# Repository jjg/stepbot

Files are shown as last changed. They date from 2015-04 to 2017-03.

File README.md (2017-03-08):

#Stepbot
A simple, printable, "turtle-style" robot platform designed to be inexpensive and easy to make.

This project is a work-in-progress, all designs, circuits, software and parts are far from release-ready.

## Materials

 * 3D printed parts
 * 2 28BYJ-48 stepper motors & controller boards (I got 5 off ebay for about $10)
 * 2 tyres (those "awareness" wristbands are probably the easiest thing to find)
 * Raspberry Pi 2 (or higher)
 * Raspberry Pi Camera Module (optional)
 * Rechargable USB battery (like the ones you use to charge a phone)

## Installation 

On top of base Rasbpian install:

    sudo apt-get install -y python python-pip python-dev

    sudo pip install rpi.gpio

Use `git` to pull down this repository or, perhaps better pull the repository down on another computer and copy the `software` directory over to the Raspberry Pi (unless you need the 3D models on the Pi for some reason).

## Test

Once the software is installed you can use the `commandlooper.py` script to test out the robot's hardware.

    sudo python commandlooper.py

The script will walk you through providing a few instructions for the robot which it will then loop through infinately.  If the hardware is setup correctly, the robot should be moving about now.  When this test is complete, use `ctrl-c` to stop the script and run 

    sudo python cleanup.py

to reset the GPIO pins to a known state.

## runmyrobot.com

There's a few more steps to getting Stepbot to work with runmyrobot.com.

First, if you have a camera, you might need this to get it to show up as a device:

    sudo modprobe bcm2835-v4l2

Next, you'll need python socketIO support:

    sudo pip install -U socketIO-client

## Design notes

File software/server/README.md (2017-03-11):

The server provides the following:

*  A websocket server located at a fixed address where robots can connect at start-up to recieve control signals
*  A destination for robot video (and other sensor) feeds
*  A web-based user interface that provides input mechanisms for robot control and renders robot sensor output

## Protocol
Robots attach to the main server websocket and send an initialization message.  The server creates a new websocket for the robot and returns a message that includes the socket port for control signals and potentially a second port to recieve sensor data.  The robot then connects to these new sockets and begins to stream sensor input to the server.  At the same time the robot prepares to receive control signals from the server.

### Control signals

## Server
The server is written in Node.js and uses the Express web framework to provide the content parts of the user interface.  It may also include forms for authenticating users, registering robots, etc.  In addition to the website, the Node.js program uses the websocket library to provide the socket interface(s) used by robots to communicate with the server.

## References

*  Streaming video over websockets: http://phoboslab.org/log/2013/09/html5-live-video-streaming-via-websockets
*  http://www.jperla.com/blog/post/capturing-frames-from-a-webcam-on-linux

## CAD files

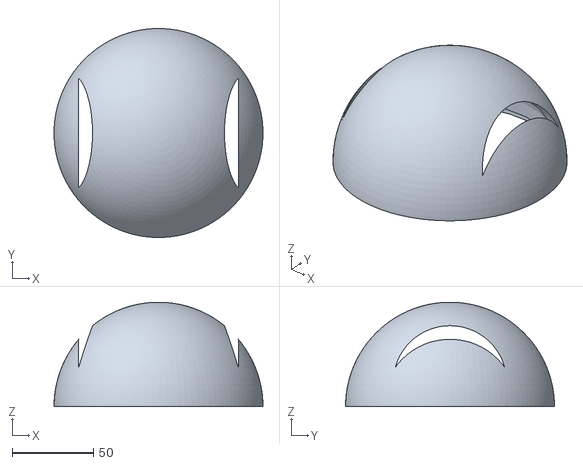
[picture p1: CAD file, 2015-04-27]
shell.stl
128.9 x 128.9 x 64.5

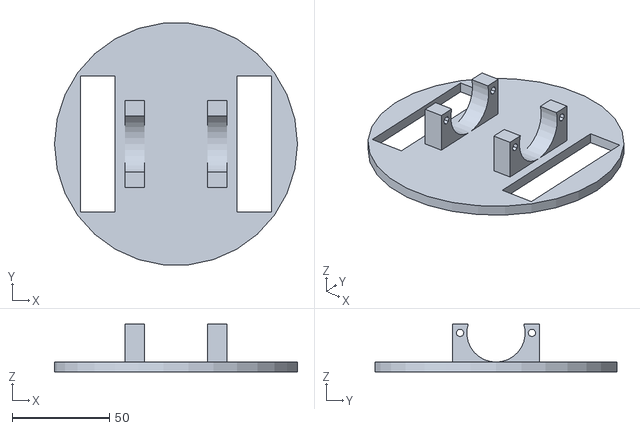
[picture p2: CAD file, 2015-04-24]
chassis3.stl
125.0 x 124.3 x 24.5

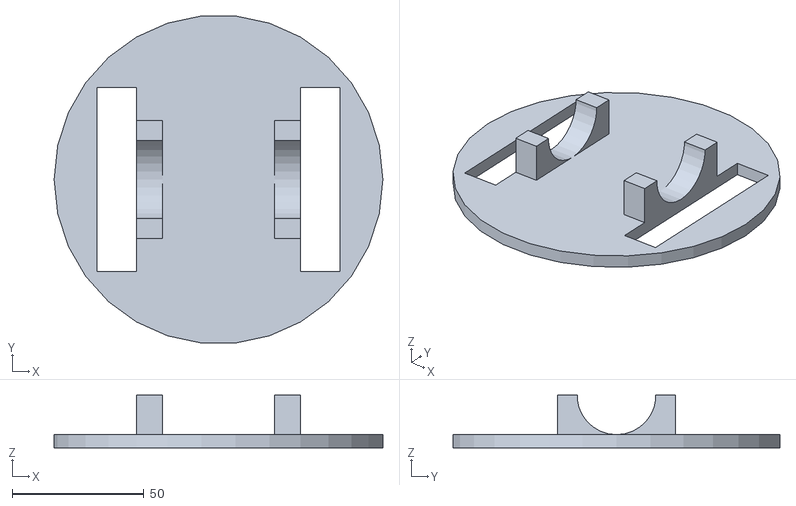
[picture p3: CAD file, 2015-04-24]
chassis.stl
125.0 x 124.3 x 20.0

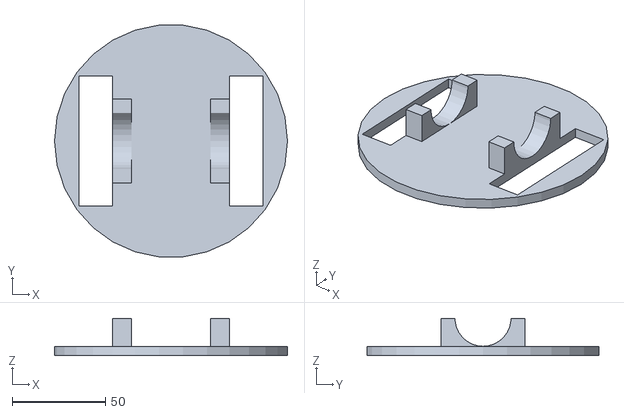
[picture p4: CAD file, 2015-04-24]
chassis2.stl
125.0 x 124.3 x 20.0

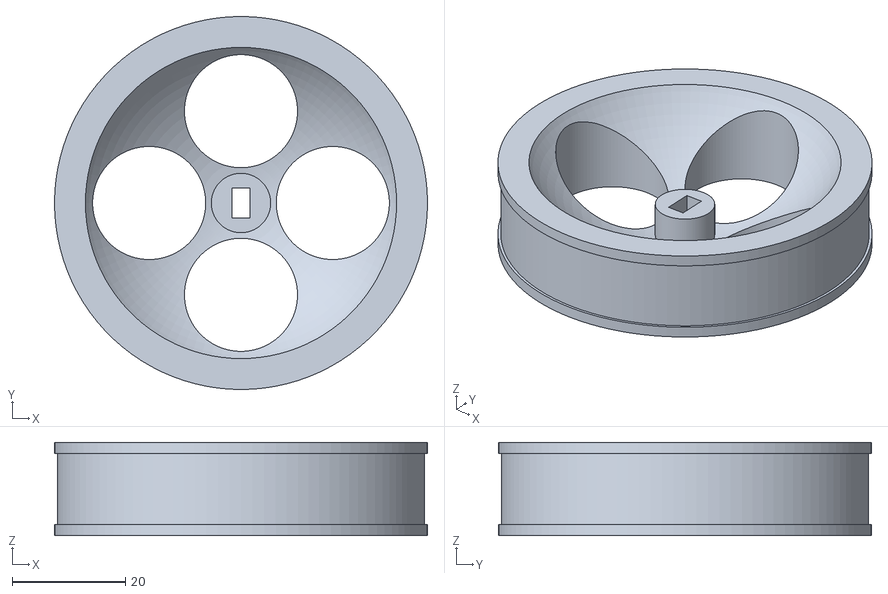
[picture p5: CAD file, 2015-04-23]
wheel4.stl
66.0 x 66.0 x 16.5

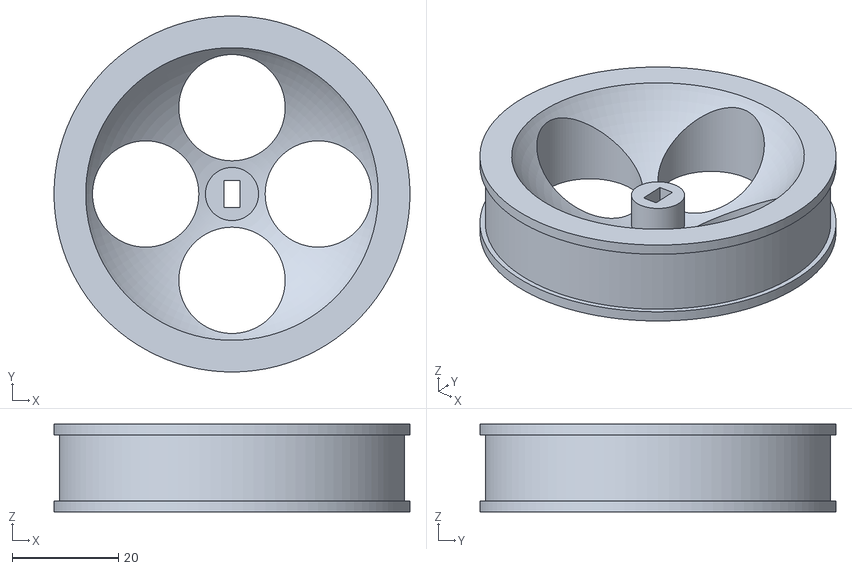
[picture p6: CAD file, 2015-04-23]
wheel.stl
67.0 x 67.0 x 16.5

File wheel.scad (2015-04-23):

outer_diameter = 65;
shaft_round_diameter = 5.25; // .25 over measured
shaft_flat_diameter = 3.25; // .25 over measured
shaft_length = 8;
tire_width = 12.5;

difference(){
	union(){
		// outside of wheel
		cylinder(r=outer_diameter / 2, h= tire_width + 2, $fn=100);

		// rim
		cylinder(r=(outer_diameter / 2) + .5, h=2, $fn=100);
		translate([0,0,tire_width + 2]){
			cylinder(r=(outer_diameter / 2) + .5, h=2, $fn=100);
		}
	}

	// shaft hole
	translate([-shaft_flat_diameter / 2,-shaft_round_diameter / 2,-1]){
		//cylinder(r=shaft_round_diameter / 2, h = tire_width + 6);
		cube([shaft_flat_diameter,shaft_round_diameter,tire_width + 6]);
	}

	// webbing
	for(i=[0:4]){
		rotate(i*360/4,[0,0,1]){
			translate([0,outer_diameter / 4,-1]){
				cylinder(r=10,h=tire_width + 6, $fn=100);
			}
		}
	}
	translate([0,0,tire_width * 2.7]){
		sphere(r=outer_diameter / 2, $fn=100);
	}
}

difference(){
	// hub
	cylinder(r=shaft_round_diameter,h=shaft_length, $fn=100);

	// shaft hole
	translate([-shaft_flat_diameter / 2,-shaft_round_diameter / 2,-1]){
		//cylinder(r=shaft_round_diameter / 2, h = tire_width + 6);
		cube([shaft_flat_diameter,shaft_round_diameter,tire_width + 6]);
	}
}

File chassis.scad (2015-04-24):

deck_diameter = 125;
deck_thickness = 5;
wheel_opening_length = 70;
wheel_opening_width = 18;
motor_diameter = 30;
motor_flange = 45;
motor_mount_width = 10;
motor_shaft_offset = 5;
motor_screw_hole = 4;
motor_screw_offset = 3.5;

difference(){

	union(){
		// main deck
		cylinder(r=deck_diameter / 2,h=deck_thickness);

		// motor mounts
		translate([-(deck_diameter/4)+motor_shaft_offset,-motor_flange/2,deck_thickness]){
			difference(){
				cube([motor_mount_width,motor_flange,motor_diameter*.65]);
				translate([-1,motor_flange/2,motor_diameter/2]){
					rotate([0,90,0]){
						#cylinder(r=motor_diameter/2,h=12);
						translate([0,(motor_diameter/2) + motor_screw_offset,0]){
							#cylinder(r=motor_screw_hole/2,h=motor_mount_width+2);
						}
						translate([0,-(motor_diameter/2) - motor_screw_offset,0]){
							#cylinder(r=motor_screw_hole/2,h=motor_mount_width+2);
						}
					}
				}
			}
		}
		translate([((deck_diameter/4)-motor_mount_width)-motor_shaft_offset,-motor_flange/2,deck_thickness]){
			difference(){
				cube([motor_mount_width,motor_flange,motor_diameter*.65]);
				translate([-1,motor_flange/2,motor_diameter/2]){
					rotate([0,90,0]){
						#cylinder(r=motor_diameter/2,h=12);
						translate([0,(motor_diameter/2) + motor_screw_offset,0]){
							#cylinder(r=motor_screw_hole/2,h=motor_mount_width+2);
						}
						translate([0,-(motor_diameter/2) - motor_screw_offset,0]){
							#cylinder(r=motor_screw_hole/2,h=motor_mount_width+2);
						}
					}
				}
			}
		}
	}

	// wheel openings
	translate([-(deck_diameter/4)-wheel_opening_width,-wheel_opening_length/2,-1]){
		cube([wheel_opening_width, wheel_opening_length, 10]);
	}
	translate([(deck_diameter/4),-wheel_opening_length/2,-1]){
		cube([wheel_opening_width, wheel_opening_length, 10]);
	}
}

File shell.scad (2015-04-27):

// basic shell
deck_diameter = 125;
wheel_opening_length = 70;
wheel_opening_width = 18;
wheel_center_above_deck = 15;

difference(){

	// outer shell
	sphere(r=(deck_diameter / 2) + 2,$fn=100);

	// deck cut-out
	translate([0,0,-1]){
		cylinder(r=deck_diameter/2,h=5);
	}

	// inner shell cut-out
	sphere(r=(deck_diameter / 2) -2);

	// bottom cut-out
	translate([-deck_diameter / 2 - 2,-(deck_diameter) / 2 -2,-deck_diameter]){
		cube([deck_diameter + 4,deck_diameter+4,deck_diameter]);
	}

	// make sure there's enough room for the wheels in motors-up arrangement
	translate([-(deck_diameter/4)-wheel_opening_width,0,wheel_center_above_deck]){
		rotate([0,90,0]){
				#cylinder(r=wheel_opening_length / 2,h=wheel_opening_width,$fn=100);
			}
	}
	translate([(deck_diameter/4),0,wheel_center_above_deck]){
			rotate([0,90,0]){
				#cylinder(r=wheel_opening_length / 2,h=wheel_opening_width,$fn=100);
			}
	}
}

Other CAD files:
wheel2.stl

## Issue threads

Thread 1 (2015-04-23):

Rim is too deep for current tyres

jjg, 2015-04-23:
Tyre rubber is too thin when stretched around the rim to reach above the ridge that holds them in.

Closed 2015-04-24.

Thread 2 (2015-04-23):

Motor shaft hole is too small

jjg, 2015-04-23:
Shaft hole is too small in both flat and round directions, approx 4.43mm long and 2.63 after printing.  Somewhat due to first layer squish, and can be cleaned-up with a file, but might be worth tweaking the model to get closer (but still respecting a tight fit).

jjg, 2015-04-23:
This is important because too much insertion force separates the bulk of the hub from the wheel.. :/

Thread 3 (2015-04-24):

Consider inverting chassis

jjg, 2015-04-24:
The chassis as-is could be used with motors above or below; motors above lowers CG, but motors below leaves a lot of chassis area open for additional components.

However, the motors have a "hump" where the wiring emerges that currently forces the hump to be facing away from the deck of the chassis, which puts the wires in a perilous place for the motors-down position.

Consider opening holes in the chassis deck to allow the motors to be positioned such that these humps can protrude through the chassis deck, allowing the wires to exit upward when in the motors-down chassis configuration.

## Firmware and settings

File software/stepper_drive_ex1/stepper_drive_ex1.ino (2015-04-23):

#include <AccelStepper.h>
#define HALFSTEP 8
#define FULLSTEP 4

// Motor pin definitions
#define motorPin1  3     // IN1 on the ULN2003 driver 1
#define motorPin2  4     // IN2 on the ULN2003 driver 1
#define motorPin3  5     // IN3 on the ULN2003 driver 1
#define motorPin4  6     // IN4 on the ULN2003 driver 1

// Initialize with pin sequence IN1-IN3-IN2-IN4 for using the AccelStepper with 28BYJ-48
AccelStepper stepper1(FULLSTEP, motorPin1, motorPin3, motorPin2, motorPin4);

void setup() {
  stepper1.setMaxSpeed(1000.0);
  stepper1.setAcceleration(100.0);
  stepper1.setSpeed(200); // 200 seems like the max at 9v
  stepper1.moveTo(20000);

}//--(end setup )---

void loop() {

  //Change direction when the stepper reaches the target position
  if (stepper1.distanceToGo() == 0) {
    stepper1.moveTo(-stepper1.currentPosition());
  }
  stepper1.run();
}

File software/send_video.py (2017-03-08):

import subprocess
import shlex
import re
import os
import time
import urllib2
import platform
import json
import sys
import base64
import random

server = "runmyrobot.com"
#server = "52.52.213.92"


from socketIO_client import SocketIO, LoggingNamespace


print "test1"


if len(sys.argv) >= 4:
    print "using dev port 8122"
    port = 8122
else:
    print "using prod port 8022"
    port = 8022

print "initializing socket io"
print "server:", server
print "port:", port
socketIO = SocketIO(server, port, LoggingNamespace)
print "finished initializing socket io"

#ffmpeg -f qtkit -i 0 -f mpeg1video -b 400k -r 30 -s 320x240 http://52.8.81.124:8082/hello/320/240/


def onHandleCameraCommand(*args):
    #thread.start_new_thread(handle_command, args)
    print args


socketIO.on('command_to_camera', onHandleCameraCommand)


def onHandleTakeSnapshotCommand(*args):
    print "taking snapshot"
    inputDeviceID = streamProcessDict['device_answer']
    snapShot(platform.system(), inputDeviceID)
    with open ("snapshot.jpg", 'rb') as f:
        data = f.read()
    print "emit"
    
    socketIO.emit('snapshot', {'image':base64.b64encode(data)})

socketIO.on('take_snapshot_command', onHandleTakeSnapshotCommand)


def randomSleep():
    """A short wait is good for quick recovery, but sometimes a longer delay is needed or it will just keep trying and failing short intervals, like because the system thinks the port is still in use and every retry makes the system think it's still in use. So, this has a high likelihood of picking a short interval, but will pick a long one sometimes."""

    timeToWait = random.choice((0.25, 0.25, 0.25, 0.25, 0.25, 0.25, 0.5, 0.5, 0.5, 0.5, 0.5, 0.5, 0.5, 0.5, 5))
    print "sleeping", timeToWait
    time.sleep(timeToWait)

    

def getVideoPort():


    url = 'http://%s/get_video_port/%s' % (server, cameraIDAnswer)


    for retryNumber in range(2000):
        try:
            print "GET", url
            response = urllib2.urlopen(url).read()
            break
        except:
            print "could not open url ", url
            time.sleep(2)

    return json.loads(response)['mpeg_stream_port']



def runFfmpeg(commandLine):

    print commandLine
    ffmpegProcess = subprocess.Popen(shlex.split(commandLine))
    print "command started"

    return ffmpegProcess
    


def handleDarwin(deviceNumber, videoPort):

    
    p = subprocess.Popen(["avconv", "-list_devices", "true", "-f", "qtkit", "-i", "dummy"], stdout=subprocess.PIPE, stderr=subprocess.PIPE)

    out, err = p.communicate()

    print err

    deviceAnswer = raw_input("Enter the number of the camera device for your robot from the list above: ")
    commandLine = 'avconv -f qtkit -i %s -f mpeg1video -b 400k -r 30 -s 320x240 http://%s:%s/hello/320/240/' % (deviceAnswer, server, videoPort)
    
    process = runFfmpeg(commandLine)

    return {'process': process, 'device_answer': deviceAnswer}


def handleLinux(deviceNumber, videoPort):

    print "sleeping to give the camera time to start working"
    randomSleep()
    print "finished sleeping"

    
    #p = subprocess.Popen(["ffmpeg", "-list_devices", "true", "-f", "qtkit", "-i", "dummy"], stdout=subprocess.PIPE, stderr=subprocess.PIPE)
    #out, err = p.communicate()
    #print err



    #os.system("v4l2-ctl -c gain=60 -c brightness=10 -c contrast=25 -c saturation=30") # Timmy
    #os.system("v4l2-ctl -c brightness=10 -c contrast=25 -c saturation=40") # Timmy
    #os.system("v4l2-ctl -c brightness=10 -c contrast=25 -c saturation=40")
    #os.system("v4l2-ctl -c brightness=240 -c contrast=75 -c saturation=60") # Skippy   
    #os.system("v4l2-ctl -c brightness=150 -c contrast=50 -c saturation=80") # Marvin
    #os.system("v4l2-ctl -c brightness=150 -c contrast=50 -c saturation=80") # Marvin
    #os.system("v4l2-ctl -c brightness=10 -c contrast=70 -c saturation=80") # RedBird
    #os.system("v4l2-ctl -c brightness=40 -c contrast=70 -c saturation=80") # ClawDaddy
    #os.system("v4l2-ctl -c brightness=50 -c contrast=50 -c saturation=80")
    #os.system("v4l2-ctl -c brightness=200 -c contrast=100 -c saturation=100")
    #os.system("v4l2-ctl -c brightness=20 -c contrast=50 -c saturation=60") # Jenny
    #os.system("v4l2-ctl -c brightness=10 -c contrast=50 -c saturation=60") # BlueberrySurprise

    if deviceNumber is None:
        deviceAnswer = raw_input("Enter the number of the camera device for your robot: ")
    else:
        deviceAnswer = str(deviceNumber)

        
    #commandLine = '/usr/local/bin/ffmpeg -s 320x240 -f video4linux2 -i /dev/video%s -f mpeg1video -b 1k -r 20 http://runmyrobot.com:%s/hello/320/240/' % (deviceAnswer, videoPort)
    #commandLine = '/usr/local/bin/ffmpeg -s 640x480 -f video4linux2 -i /dev/video%s -f mpeg1video -b 150k -r 20 http://%s:%s/hello/640/480/' % (deviceAnswer, server, videoPort)
    # For new JSMpeg
    commandLine = '/usr/bin/avconv -f video4linux2 -framerate 25 -video_size 640x480 -i /dev/video%s -f mpegts -codec:v mpeg1video -s 640x480 -b:v 250k -bf 0 http://%s:%s/hello/640/480/' % (deviceAnswer, server, videoPort) # ClawDaddy
    #commandLine = '/usr/local/bin/ffmpeg -s 1280x720 -f video4linux2 -i /dev/video%s -f mpeg1video -b 1k -r 20 http://runmyrobot.com:%s/hello/1280/720/' % (deviceAnswer, videoPort)
    #commandLine = '/usr/bin/avconv -f video4linux2 -framerate 25 -video_size 640x480 -i /dev/video%s -f mpegts -codec:v mpeg1video -s 640x480 -b:v 250k -bf 0 http://%s:%s/hello/640/480/' % (deviceAnswer, server, videoPort) # Stepbot 

    process = runFfmpeg(commandLine)

    return {'process': process, 'device_answer': deviceAnswer}


def handleWindows(deviceNumber, videoPort):

    p = subprocess.Popen(["avconv", "-list_devices", "true", "-f", "dshow", "-i", "dummy"], stdout=subprocess.PIPE, stderr=subprocess.PIPE)
    
    
    out, err = p.communicate()
    
    lines = err.split('\n')
    
    count = 0
    
    devices = []
    
    for line in lines:
    
        #if "]  \"" in line:
        #    print "line:", line
    
        m = re.search('.*\\"(.*)\\"', line)
        if m != None:
            #print line
            if m.group(1)[0:1] != '@':
                print count, m.group(1)
                devices.append(m.group(1))
                count += 1
    

    if deviceNumber is None:
        deviceAnswer = raw_input("Enter the number of the camera device for your robot from the list above: ")
    else:
        deviceAnswer = str(deviceNumber)

    device = devices[int(deviceAnswer)]
    commandLine = 'avconv -s 320x240 -f dshow -i video="%s" -f mpeg1video -b 200k -r 20 http://%s:%s/hello/320/240/' % (device, server, videoPort)
    

    process = runFfmpeg(commandLine)

    return {'process': process, 'device_answer': device}
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

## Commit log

2015-04-23 added extended hub and smoothed everything
    [wheel.scad, wheel.stl]
2015-04-23 created directory for software and began basic stepper control experiments
2015-04-23 increased shaft hole size and decreased rim depth
    [wheel.scad, wheel2.stl]
2015-04-23 reduced wheel motor shaft size and added initial chassis model
    [chassis.scad, wheel.scad, wheel3.stl]
2015-04-24 first version of chassis done
    [chassis.scad]
2015-04-24 chassis models added
    [chassis.stl, chassis2.stl]
2015-04-24 recess motor mounts 5mm to add clearance for motor flange, non-flat motor shaft
    [chassis.scad]
2015-04-24 increased motor mount height to meet mounting screw holes, and added screw holes
    [chassis.scad, chassis3.stl]
2015-04-24 added output files for latest wheel design
    [wheel4.stl]
2015-04-24 added basic shell design
    [shell.scad, shell.stl]
2015-04-27 added inside ridge to shell to fit over deck
    [shell.scad, shell.stl]
2017-02-25 Flip step sequence for second motor as its reversed compared to motor 1.
2017-02-25 Add experimental support for second motor.
